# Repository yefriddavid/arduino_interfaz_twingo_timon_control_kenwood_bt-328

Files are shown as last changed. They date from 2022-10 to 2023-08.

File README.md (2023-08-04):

# Arduino Interfaz Twingo Timon Control Kenwood BT-328

### References:
- https://www.kenwood.com/pa/car/head_units/kmm-bt328/
- https://articulo.mercadolibre.com.co/MCO-555947676-control-de-audio-ve-interfaz-para-twingo-clio-y-symbol-_JM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
- https://github.com/bigevtaylor/arduino-swc
- https://www.instructables.com/Custom-Arduino-to-Keep-CAN-Steering-Wheel-Buttons-/
- https://www.youtube.com/watch?v=epe_4fnpTjk&ab_channel=JustinNelson%27sProjects
- https://github.com/tsprlng/toyota-kenwood-adaptor ## works
- http://drclone.blogspot.com/2015/01/controlar-autorradio-sony-con-los.html
- https://www.youtube.com/watch?v=6VO589mRQkM&ab_channel=TravisColesen
- https://www.youtube.com/watch?v=RdR43ACfeu8&t=257s&ab_channel=MentalidadDeIngenier%C3%ADa
- https://www.youtube.com/watch?v=d-j0onzzuNQ&t=305s&ab_channel=TheEngineeringMindset
- https://lastminuteengineers.com/esp8266-pinout-reference/
- https://randomnerdtutorials.com/esp8266-pinout-reference-gpios/
- https://www.kenwood.com/asia/car/Steering-remote/
- https://www.youtube.com/watch?v=fk73SCOE8qU&ab_channel=BartKuijper
- https://pastebin.com/fXbScxV4 // code with jvc and twingo
- https://init6.pomorze.pl/projects/kenwood_ford/

### Pinout
- https://lastminuteengineers.com/esp8266-pinout-reference/
- https://lededitpro.com/esp8266-pinout-guide-gpios/

### 

- https://www.youtube.com/watch?v=vRJ6ywV8bLI&ab_channel=Electr%C3%B3nicaAWV
- https://randomnerdtutorials.com/esp8266-pinout-reference-gpios/

### Commands
```
$ make upload
$ make compile
$ make just-compile
```

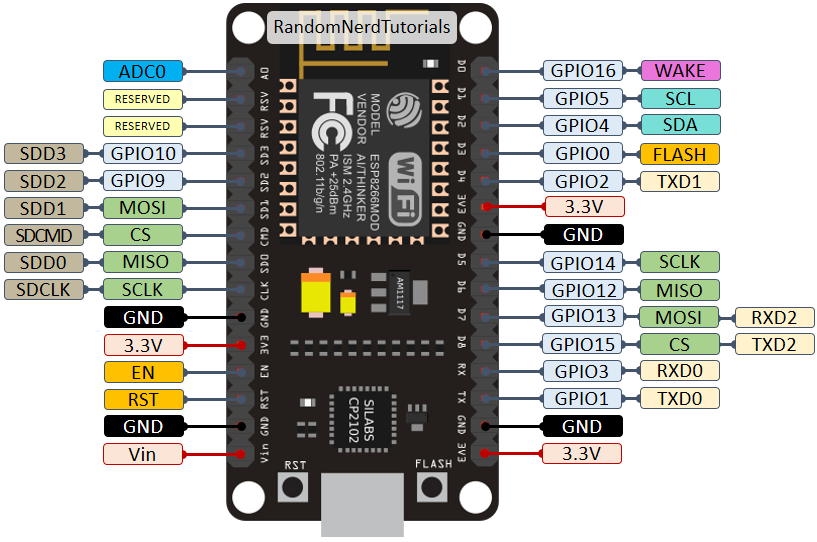
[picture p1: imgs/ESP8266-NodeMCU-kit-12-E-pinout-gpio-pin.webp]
ESP8266 Pins schema


| Pin		| Arnes Color 	| ESP8266 Pin	| Card	Control Color	|
|---|---|---|---|
| 4		| 	Green		| 	D2 	|	Green 		|
| 2	 	| 	White 		|	D4 	|	Brown 		|
| 15 	 	| 	Yellow		|	D8 	|	Yellow 		|
| 12 	 	| 	Blue		|	D6 	|	Light Blue 	|
| 13 		| 	White/Brown 	|	D7 	|	Black		|		
| 14 	 	| 	White/Orange 	|	D5 	|	Red 		|

| 	 Wire 	| Brown 	| 	Blak	| 	Red	|
|---|---|---|---|
| 	Green		| RULETA	| SKIP_FORWARD  | SOURCE |
| 	Yellow		| RULETA	| SKIP_BACKWARD  | VOL DOWN |
| 	Blue		| RULETA 	| MUTE | VOL UP |

```

D4 -> 2
D8 -> 15
D2 -> 4
D6 -> 12
D5 -> 14
D1 -> 5 -> Stereo Output -> kenwood

```

```
Red Wire -> Ignition stereo car
Black Wire -> Negative Stereo Wire harness
Yellow Wire -> light/blue Wire Stero Harness

```

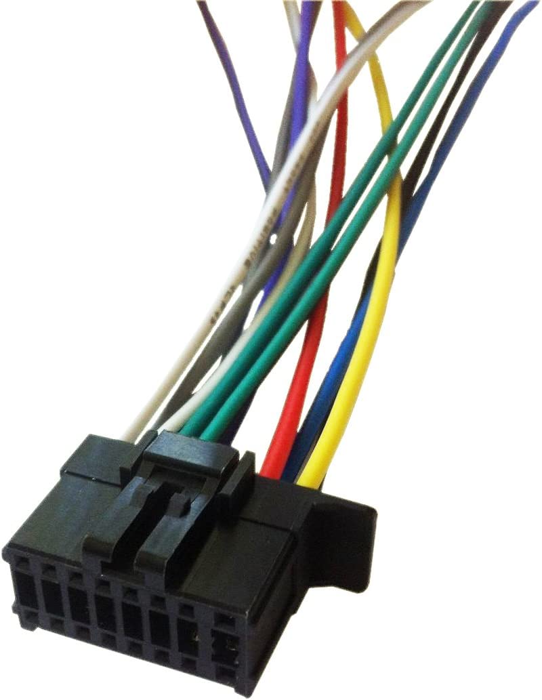
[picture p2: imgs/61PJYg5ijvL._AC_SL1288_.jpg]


### Command
<!--![Alt text](D_NQ_NP_670314-MLV45242759239_032021-O.jpg "ESP8266 Kenwood wires schema")-->

### Twingo Access

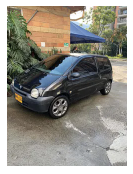
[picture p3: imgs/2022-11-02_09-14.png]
Twingo Access 2012


## New features
- beep: to know if the device started, from driver's seat

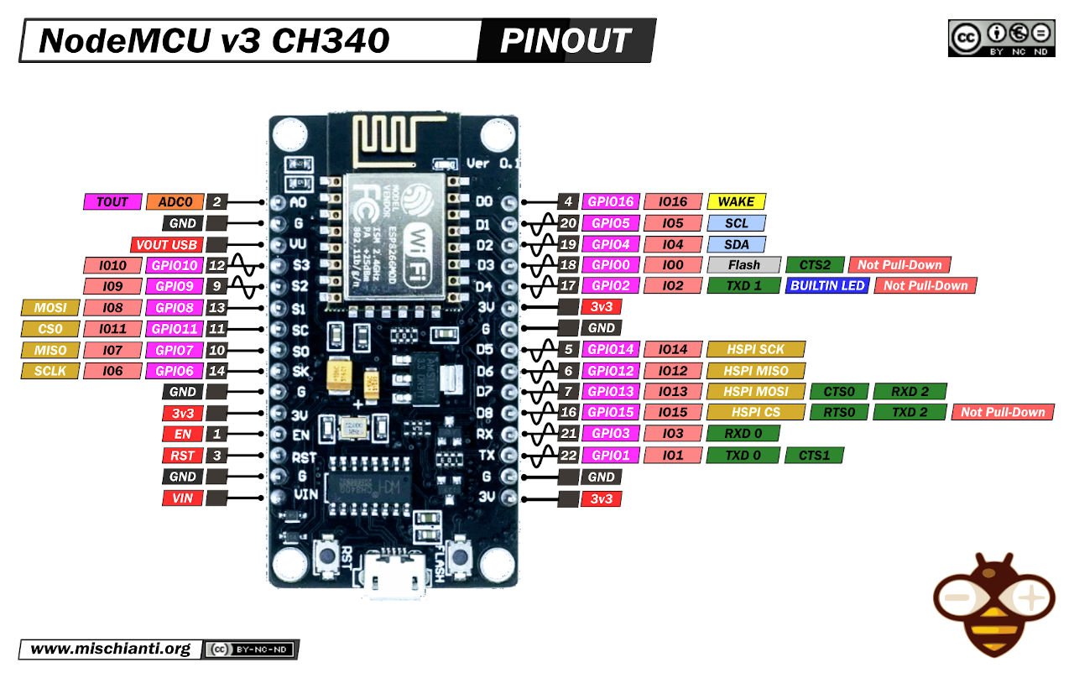
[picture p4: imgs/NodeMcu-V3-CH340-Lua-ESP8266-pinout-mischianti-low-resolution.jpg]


## Green Output (OK) only works for leds or something like
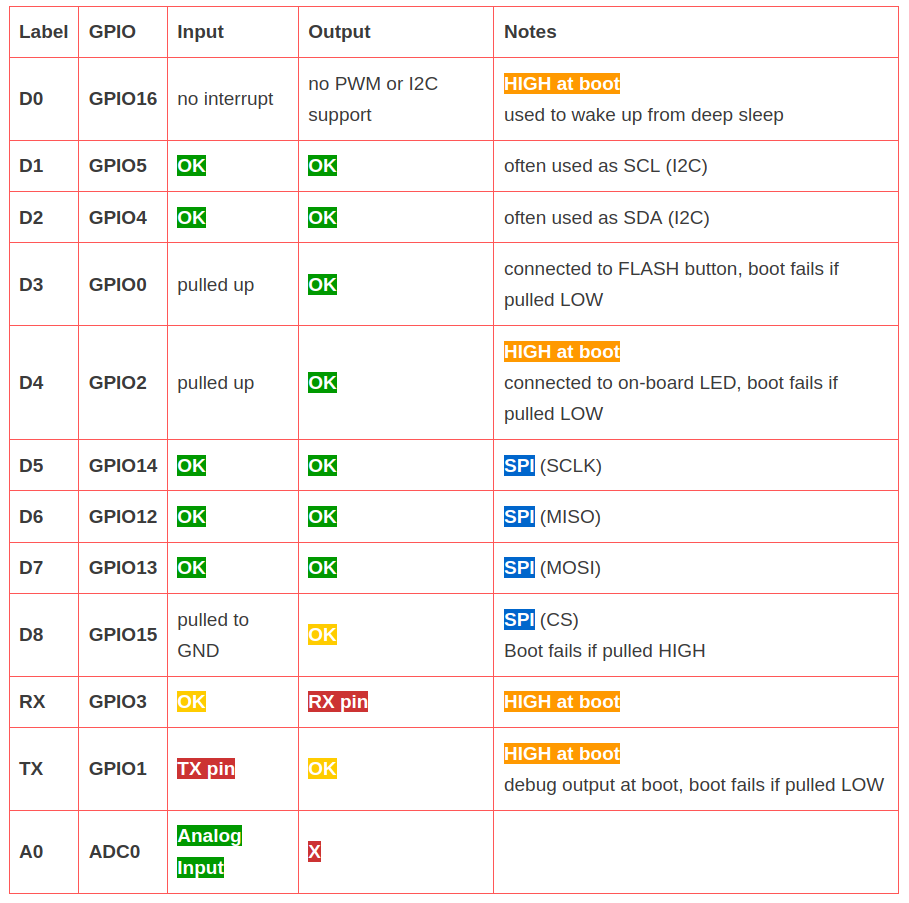
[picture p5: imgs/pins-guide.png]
Pins Guide


## Kendood BT-328
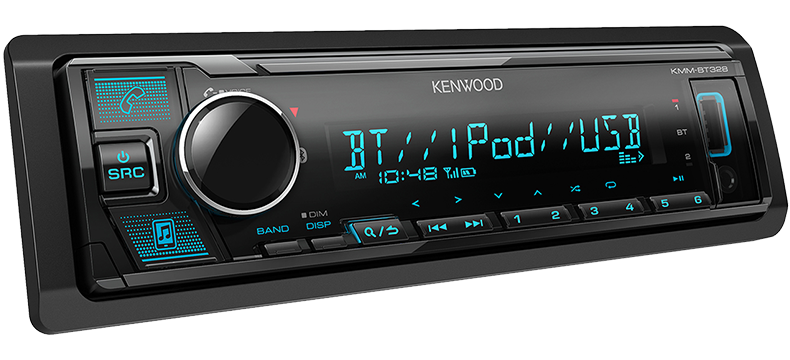
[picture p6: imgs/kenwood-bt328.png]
Kenwood BT328


## Twingo Timon Control
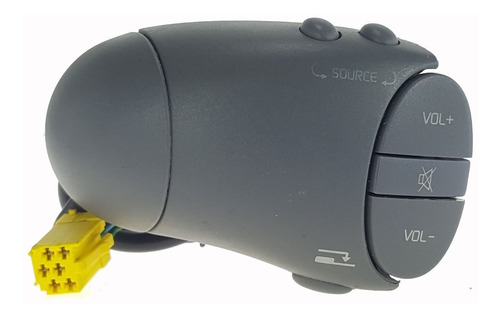
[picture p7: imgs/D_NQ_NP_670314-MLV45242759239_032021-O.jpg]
Twingo Control


## Case
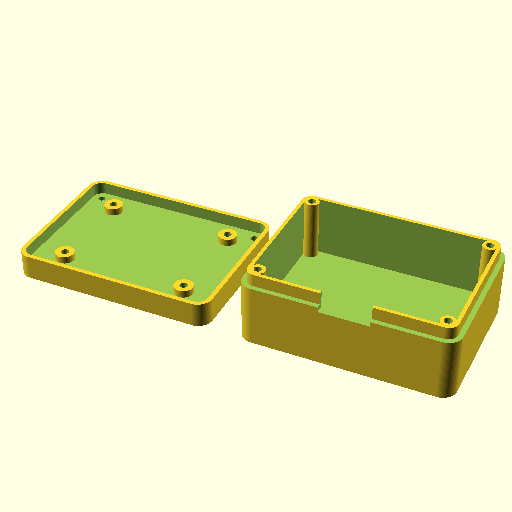
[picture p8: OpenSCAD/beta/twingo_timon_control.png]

## Wire
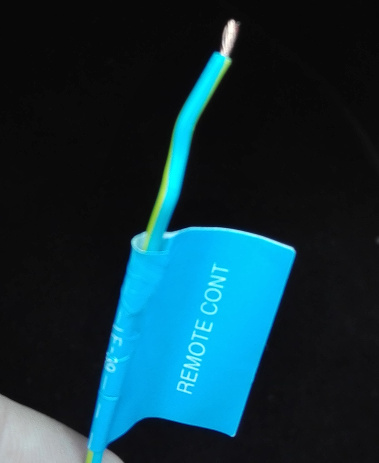
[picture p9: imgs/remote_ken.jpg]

## NEC
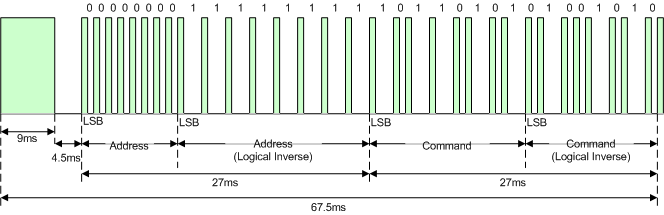
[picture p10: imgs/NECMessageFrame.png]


## PCB
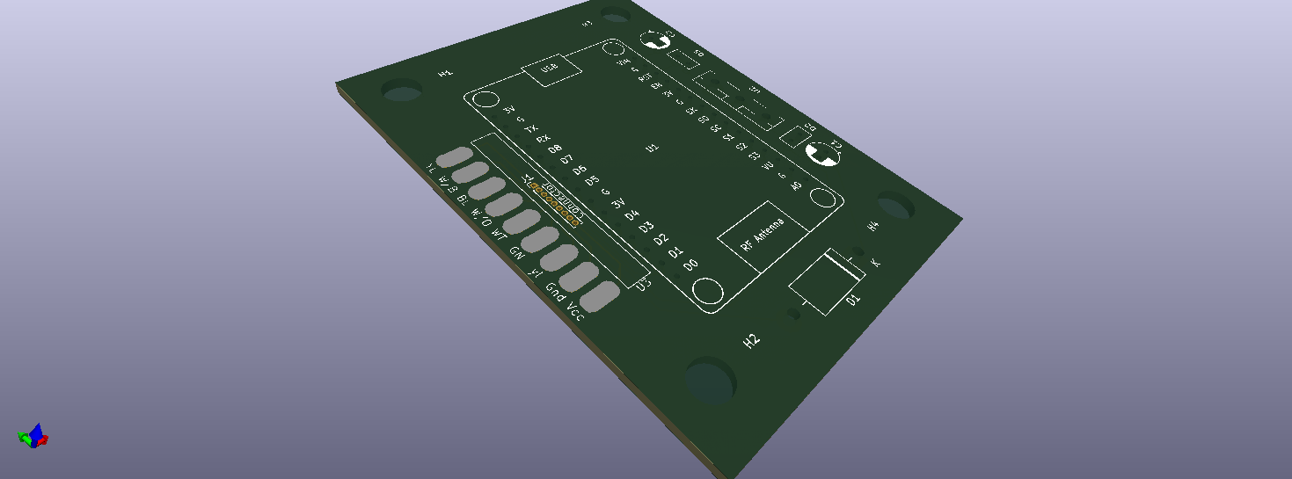
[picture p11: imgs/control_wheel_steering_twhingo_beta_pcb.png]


## PINOUT PWM
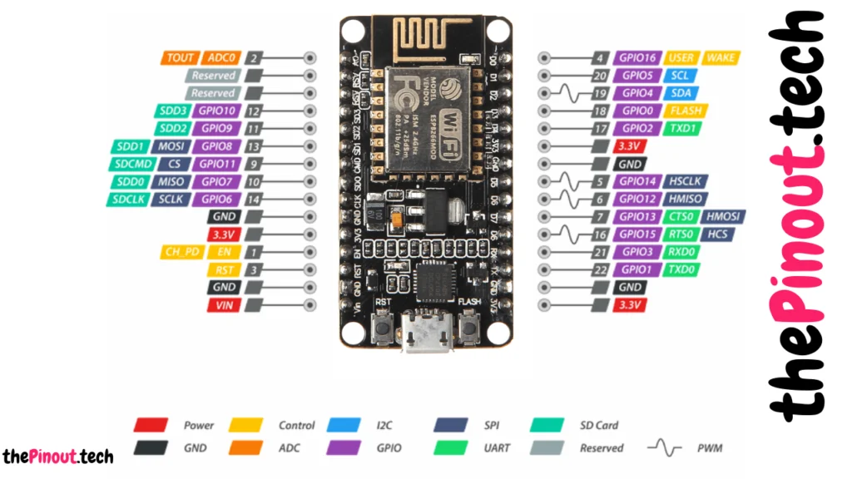
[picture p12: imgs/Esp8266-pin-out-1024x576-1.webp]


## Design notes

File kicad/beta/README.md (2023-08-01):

preguntas cristian

Regulador integrarlo o externo? temperatura del carro, ineficiente que es el actual.
pistas y caja en 3D

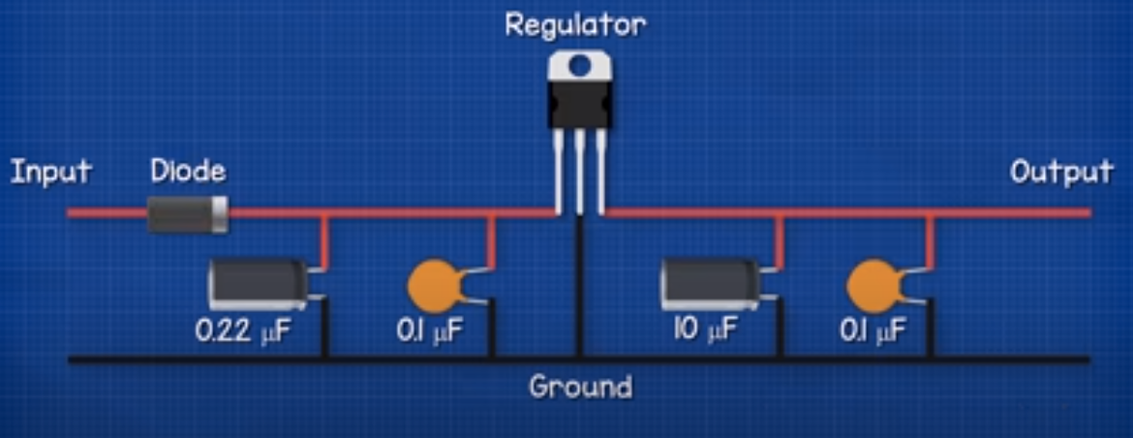
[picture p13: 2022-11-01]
imgs/schema-regulator.png

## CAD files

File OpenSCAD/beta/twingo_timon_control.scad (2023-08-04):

$fn=100;


//aspen = "gray";
//almond = "white";
//pine = "green";
//banyan="red";
//aspen = "";
aspen = "";//rgb(255, 0, 0);
almond = "";

pine = "";
banyan="";
altoSoporte = 3;



w=78; // Width
h=56; // Higth
d=25; //
wt=3.5;
bpt=5;
tpt=5;
cd=5;
cwt=1.5;

echo(d+bpt+tpt);
translate([-w/2-10,0,d+bpt+tpt+1])
rotate(a=180, v=[0,1,0])
lid();


translate([w/2+20,0,0])
box();


cx=0;
cy=0;
chs_i=1.5;
chs_o=4;
dsth=3;
chd_h=90;
chd_v=90;
tolerancia3D=0.3;
tolerancia=-0.2;
//--------------------------------------------------
//TOP PART MOUNTING HOLES
//--------------------------------------------------
//position
cx1=0;
cy1=0;
//holes size (radius)
chs_i1=1.6;
chs_o1=3;
//holes distance h
chd_h1=h-2*chs_i1-2;
//holes distance v
chd_v1=w-2*chs_i1-2;
//*************************************************//
//*************************************************//
//MODULES
//*************************************************//

//top box part
module lid()
{
        difference()
        {
            union()
            {
                difference()
                {
                    translate([ 0, 0, d+bpt-cd-0.2])
                    rounded_cube( w+2*wt, h+2*wt, tpt+cd+0.2, 6);

                    translate([ 0, 0,  d+bpt-cd-1])
                    rounded_cube( w+2*cwt+0.3, h+2*cwt+0.3, cd+1, 4);
                }
                /*************************/

                //add here...

                /*************************/
            }
            //TOP PART HOLES
            lid_hols();
            /*************************/

            //subtract here...

            lid_laterals_holes();
            /*************************/
	        lid_postes_holes_tuercas();
        }
    difference()
    {
        lid_postes();
	    lid_postes_holes();

    }
}

//bottom box
module box()
{
    difference()
    {
        union()
        {
            difference()
            {
                rounded_cube( w+2*wt, h+2*wt, d+bpt, 6);

                translate([ 0, 0, -cd])
                difference()
                {
                    translate([ 0, 0,  d+bpt])
                    rounded_cube( w+2*wt+1, h+2*wt+1, cd+1, 4);

                    translate([ 0, 0,  d+bpt-1])
                    rounded_cube( w+2*cwt, h+2*cwt, cd+3, 4);
                }
                translate([ 0, 0, bpt])
                rounded_cube( w, h, d+bpt, 4);
            }
            //BOARD DISTANCER
            //board_distancer();
            //TOP PLATE DISTANCER
            top_distancer();
            /*************************/

            //add here...

            /*************************/
        }

        //BOARD HOLES
        // bh_cut();
        //TOP PART HOLES
	// holes postes box
        tph_b_cut();
             box_laterals_holes();
        /*************************/

        //subtract here...

        /*************************/

    }

    //box_laterals_holes(); //preview
    // :w
    // soportes();
    left_support(40,40,3,5);
    right_support(40,40,3,5);

}

module left_support(side1,side2,corner_radius,triangle_height){
    translate([-77,0,0]){
    difference(){
  translate([5,0,0]){
    hull(){
    translate([17,0,0]) cylinder(r=corner_radius,h=triangle_height-1);
      x=side1 - corner_radius * 2;
      y=side2 - corner_radius * 2+5;
      echo(y);
    translate([x,-y+25,0]) cylinder(r=corner_radius,h=triangle_height-1);
    translate([x,y-25,0]) cylinder(r=corner_radius,h=triangle_height-1);
    }
  }

  // hole
  translate([28,0,-1])
//color("red")
cylinder(r=1.75,h=60);

    // base tornillo
  translate([28,0,3.5])
    cylinder(r=4,h=60);
  }
  }
}

module right_support(side1,side2,corner_radius,triangle_height){

    val = 10;

    x=side1 - corner_radius * 2 + val;
    y=side2 - corner_radius * 2+5;
    echo(x);
      translate([-25,0,0]){
    difference(){
  translate([15,0,0]){
    hull(){
    translate([63,0,0]) cylinder(r=corner_radius,h=triangle_height-1); // middle square

      //echo(y);
    translate([x,-y+25,0]) cylinder(r=corner_radius,h=triangle_height-1);
    translate([x,y-25,0]) cylinder(r=corner_radius,h=triangle_height-1);
    }
  }

  // hole
  translate([73,0,-1])
//color("red")
cylinder(r=1.75,h=60);
    // base tornillo
  //translate([28,0,3.5])
    //cylinder(r=4,h=60);
  translate([73,0,3.5])
cylinder(r=4,h=60);
  }
  }
}


module box_laterals_holes()
{
    translate([cx,cy,0])
    {
// x, y, z
        //ancho=25; // -13
        ancho=20; // -8

        x = ancho/2*-1;
        translate([x,-34,20])
        cube([ancho,10,11]);
        // original translate([+chd_h/2+-62,-34,23]) cube([ancho,10,8]);

    }

}
/****************************************************/
module lid_laterals_holes()
{
    translate([cx,cy,0])
    {

        translate([+chd_h/2-99,-10,24]) cube([3,19,5]);

    }
}
module lid_postes()
{

    translate([cx,cy,0])
    {

        z = 27;
        z = 29-altoSoporte;
        //z = 21;
        y1 = 19.5;// chd_v/2-25.5;
        //y2 = -chd_v/2+25.5;
        y2 = -19.5;
        alto=altoSoporte+dsth;
        echo("alto");
        echo(alto);

        correccion=7.5;
        //x2=-chd_h/2+18;
        x2=-28.5;// (w/4+correccion);
        //x1=+chd_h/2-18;
        //x1=+chd_h/2-18;
        // x1=w/4+correccion;
        x1=28.5;

        color(aspen) translate([x1,y1,z]) cylinder(r=chs_o,h=alto);
        color(pine) translate([x2,y1,z]) cylinder(r=chs_o,h=alto);
        color(almond) translate([x1,y2,z]) cylinder(r=chs_o,h=alto);
        color(banyan) translate([x2,y2,z]) cylinder(r=chs_o,h=alto);

    }


}

// Postes box
module top_distancer()
{
    translate([cx1,cy1,0])
    {
        translate([-chd_v1/2, chd_h1/2, 0])
        cylinder(r=chs_o1,h=d+bpt);
        translate([-chd_v1/2, -chd_h1/2, 0])
        cylinder(r=chs_o1,h=d+bpt);
        translate([chd_v1/2, chd_h1/2, 0])
        cylinder(r=chs_o1,h=d+bpt);
        translate([chd_v1/2, -chd_h1/2, 0])
        cylinder(r=chs_o1,h=d+bpt);
    }
}
module lid_postes_holes_tuercas()
{
    translate([cx,cy,0])
    {

        x=chd_h/2-16.5;
        translate([x,chd_v/2-25.5,35]) fhex(5.5,12);
        translate([-x,chd_v/2-25.5,35]) fhex(5.5,12);
        translate([-x,-chd_v/2+25.5,35]) fhex(5.5,12);
        translate([x,-chd_v/2+25.5,35]) fhex(5.5,12);

    }
}
module lid_postes_holes()
{
    translate([cx,cy,0])
    {

        // el tornillo tiene un diametro de 3 mas la tolerancia 0.3 => 3.3 / 2 = R
        translate([+chd_h/2-16.5,chd_v/2-25.5,24]) cylinder(r=1.65,h=bpt+dsth+2);
        translate([-chd_h/2+16.5,chd_v/2-25.5,24]) cylinder(r=1.65,h=bpt+dsth+2);
        translate([+chd_h/2-16.5,-chd_v/2+25.5,24]) cylinder(r=1.65,h=bpt+dsth+2);
        translate([-chd_h/2+16.5,-chd_v/2+25.5,24]) cylinder(r=1.65,h=bpt+dsth+2);
    }
}

module lid_hols()
{
    translate([cx1,cy1,0])
    {
        translate([-chd_v1/2, chd_h1/2, -2]) cylinder(r=chs_i1,h=d+bpt+tpt+3);
        translate([chd_v1/2, chd_h1/2, -2]) cylinder(r=chs_i1,h=d+bpt+tpt+3);

        translate([-chd_v1/2, -chd_h1/2, -2]) cylinder(r=chs_i1,h=d+bpt+tpt+3);
        translate([chd_v1/2, -chd_h1/2, -2])  cylinder(r=chs_i1,h=d+bpt+tpt+3);


        translate([-chd_v1/2, chd_h1/2, d+bpt+tpt-1.3])
        fhex(5.5,3);

        translate([chd_v1/2, chd_h1/2, d+bpt+tpt-1.3])
        fhex(5.5,3);

        translate([-chd_v1/2, -chd_h1/2, d+bpt+tpt-1.3])
        fhex(5.5,3);

        translate([chd_v1/2, -chd_h1/2, d+bpt+tpt-1.3])
        fhex(5.5,3);

    }
}
module tph_b_cut()
{
    translate([cx1,cy1,0])
    {
        // translate([-chd_v1/2, chd_h1/2, -2]) cylinder(r=chs_i1,h=d+bpt+3);
        translate([-chd_v1/2, chd_h1/2, -2]) cylinder(r=chs_i1,h=d+bpt+3);
        translate([chd_v1/2, chd_h1/2, -2]) cylinder(r=chs_i1,h=d+bpt+3);

        translate([-chd_v1/2, -chd_h1/2, -2]) cylinder(r=chs_i1,h=d+bpt+3);
        translate([chd_v1/2, -chd_h1/2, -2]) cylinder(r=chs_i1,h=d+bpt+3);

        translate([-chd_v1/2, chd_h1/2, -1]) cylinder(r=3,h=4);

        translate([chd_v1/2, chd_h1/2, -1]) cylinder(r=3,h=4);

        translate([-chd_v1/2, -chd_h1/2, -1]) cylinder(r=3,h=4);

        translate([chd_v1/2, -chd_h1/2, -1]) cylinder(r=3,h=4);

    }
}


module rounded_cube( x, y, z, r)
{
    translate([-x/2+r,-y/2+r,0])
    linear_extrude(height=z)
    minkowski()
    {
        square([x-2*r,y-2*r],true);
        translate([x/2-r,y/2-r,0])
        circle(r);

    }
}

module fhex(wid,height)
{
    hull()
    {
        cube([wid/1.7,wid,height],center = true);
        rotate([0,0,120])cube([wid/1.7,wid,height],center = true);
        rotate([0,0,240])cube([wid/1.7,wid,height],center = true);
    }
}

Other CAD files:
OpenSCAD/beta/generic_box_v2.scad

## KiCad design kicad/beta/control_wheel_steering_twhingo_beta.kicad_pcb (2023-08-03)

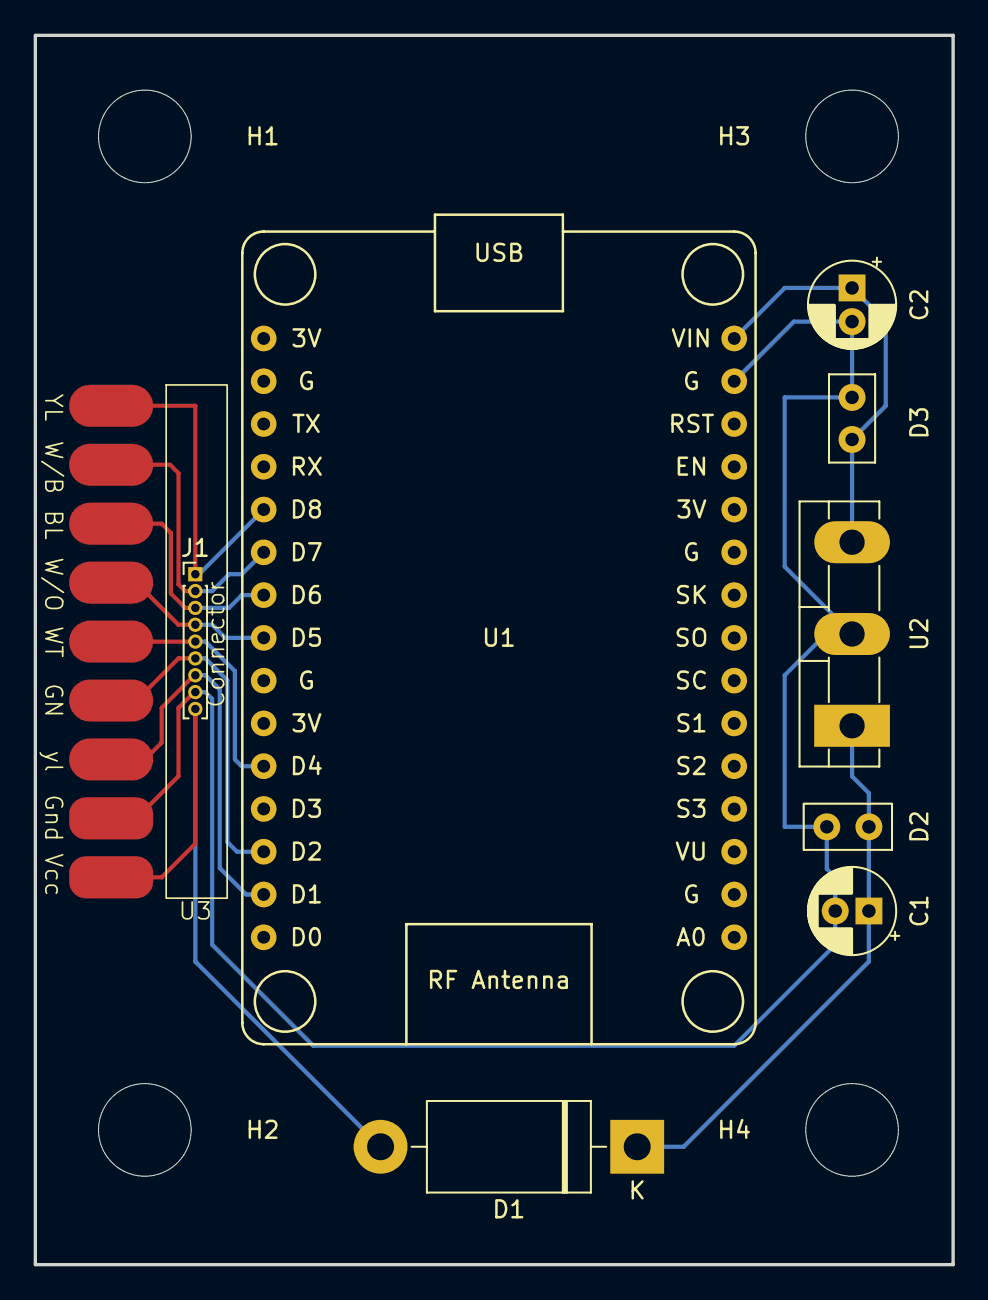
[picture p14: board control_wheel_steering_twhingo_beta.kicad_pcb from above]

Board: 2 copper layers, 54.5 x 73.0 mm, 13 parts (0 on the bottom side), 9 nets.

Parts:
C1: Cap2; CP_Radial_D5.0mm_P2.00mm
C2: C_Polarized; CP_Radial_D5.0mm_P2.00mm
D1: 1N5408; D_DO-201AD_P15.24mm_Horizontal
D2, D3: cap1; C_Disc_D5.0mm_W2.5mm_P2.50mm
H1, H2, H3, H4: MountingHole; MountingHole_5.5mm
J1: Conn_01x09_Socket; PinHeader_1x09_P1.00mm_Vertical
U1: NodeMCU_1.0_(ESP-12E); NodeMCU1.0(12-E)
U2: L7805; TO-3P-3_Vertical
U3: Twingo_Timon_Control_Connector

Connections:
D2Green: J1.6, U3.6 (D2)
D4-White: J1.5, U3.5 (D4)
D5-White/Orange: J1.4, U3.4 (D5)
D6-Blue: J1.3, U3.3 (D6)
D7-WhiteBrown: J1.2, U3.2 (D7)
D8-Yellow: J1.1, U3.1 (D8)
Gnd: J1.8, U3.8 (GND)
StereoOut: J1.7, U3.7 (StrOut)
VinCar: J1.9, U3.9 (Vin)

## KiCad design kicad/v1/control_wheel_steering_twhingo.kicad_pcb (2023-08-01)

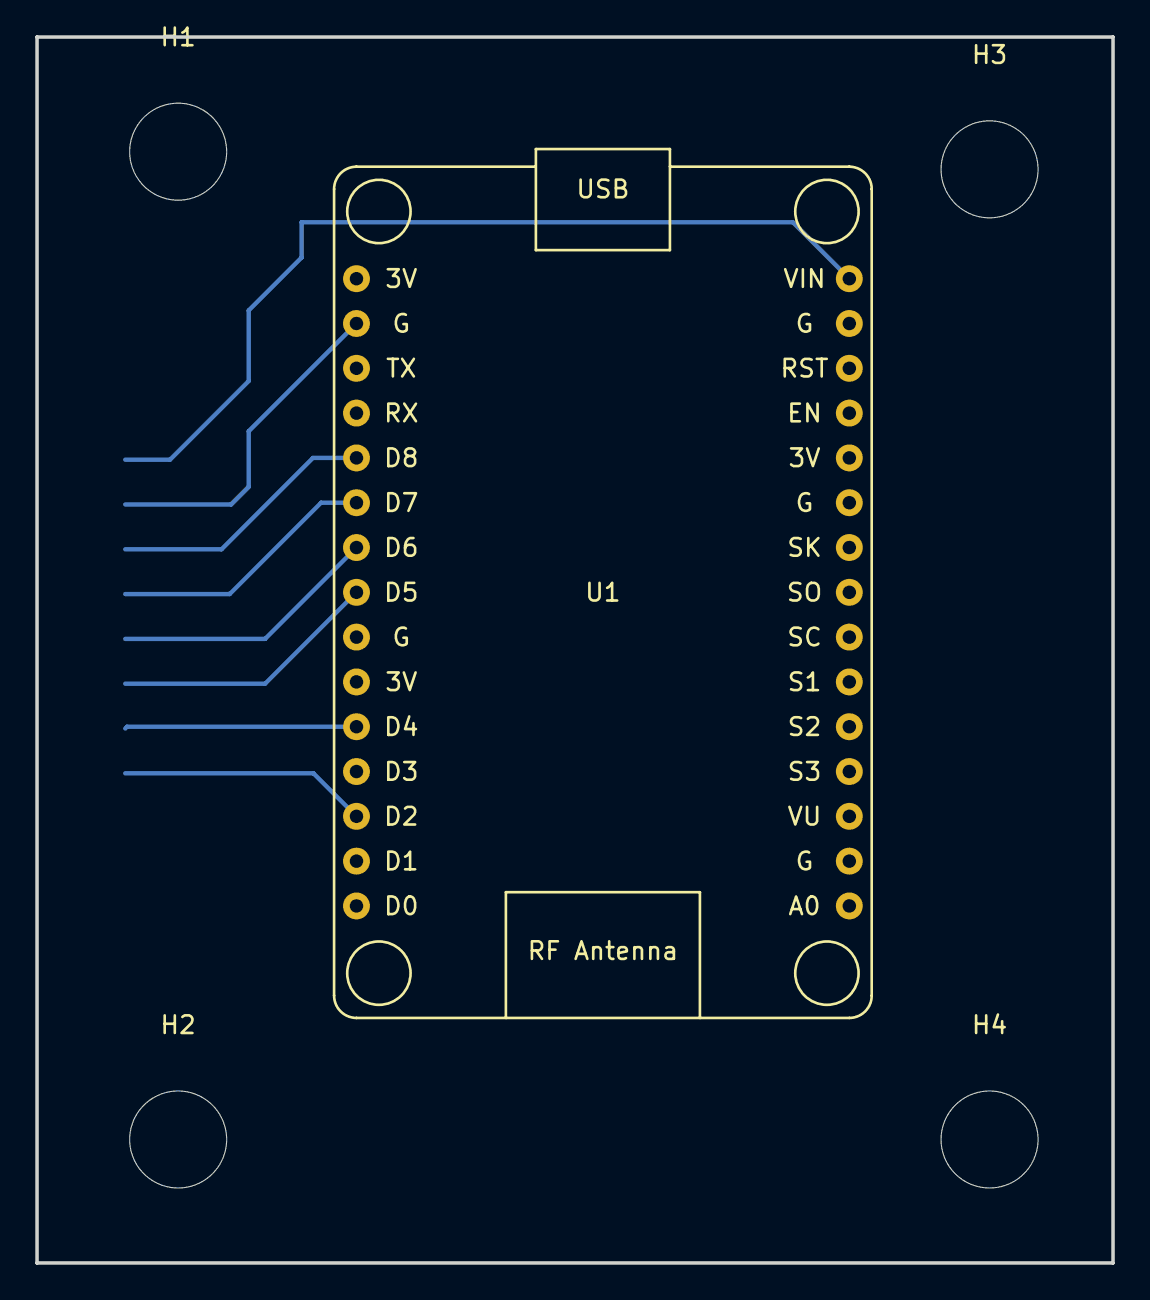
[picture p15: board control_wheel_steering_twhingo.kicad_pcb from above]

Board: 2 copper layers, 61.0 x 69.5 mm, 6 parts (1 on the bottom side), 8 nets.

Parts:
H1, H2, H3, H4: MountingHole; MountingHole_5.5mm
J1: Conn_01x09_Socket; Harting_har-flexicon_14110813010xxx_1x08-MP_P2.54mm_Horizon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
U1: NodeMCU_1.0_(ESP-12E); NodeMCU1.0(12-E)

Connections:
D2-White: J1.8, U1.28 (D2(GPIO4))
D4-Brawn: J1.7, U1.26 (D4(GPIO2))
D5-Red: J1.6, U1.23 (D5(GPIO14))
D6-Blue: J1.5, U1.22 (D6(GPIO12))
D7-White/Orange: J1.4, U1.21 (D7(GPIO13))
D8-Yellow: J1.3, U1.20 (D8(GPIO15))
GND: J1.2, U1.17 (GND)
Vin: J1.1, U1.15 (VIN)

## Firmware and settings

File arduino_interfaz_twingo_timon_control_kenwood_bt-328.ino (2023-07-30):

/* 				Twingo Stering Wheel Audio Stereo Contro For Keenwood 					*/
/*------------------+---------------+-------------------+-----------------------+---------------+-----------------------+*/
/*================= | Code Variable |	    Pin		|     Arnes Color 	|   Board Pin 	| 	Control Color	|*/
/*------------------+---------------+-------------------+-----------------------+---------------+-----------------------+*/
static const uint8_t pinVerde 	 = 	4; 	// 	| 	Green		| 	D2 	|	Green 		|
static const uint8_t pinMarron 	 = 	2; 	// 	| 	White 		|	D4 	|	Brown 		|
static const uint8_t pinAmarillo = 	15; 	// 	| 	Yellow		|	D8 	|	Yellow 		|
static const uint8_t pinAzul 	 = 	12; 	// 	| 	Blue		|	D6 	|	Light Blue 	|
static const uint8_t pinNegro 	 = 	13; 	//	| 	White/Brown 	|	D7 	|	Black		|
static const uint8_t pinRojo 	 = 	14; 	// 	| 	White/Orange 	|	D5 	|	Red 		|
/*------------------------------------------------------+---------------+---------------+-------------------------------+*/

static const uint8_t stereoOutput = 5; // output -> yellow D1

int azul;
int verde;
int rojo;
int negro;
int amarillo;
int marron, ruletaSiguiente, ruletaAnterior, ruletaActual;
int pulsado, mantiene;

static int ZERO = 0;
static int VOL_UP = 1;
static int VOL_DOWN = 2;
static int SKIP_BACKWARD = 3;
static int SKIP_FORWARD = 4;
static int PLAY_PAUSE = 5;
static int MUTE = 6;
static int SOURCE = 7;

const String KenwoodCommDescriptionArray[10] = {
  "zero",
  "Volume up",
  "Volume down",
  "Skip forward",
  "Skip backward",
  "Play/pause",
  "Mute",
  "Source"
};

void setup()
{

  // Por defecto los pins de entrada en HIGH (PULLUP)
  pinMode(pinMarron, INPUT_PULLUP); 	// for wheel
  pinMode(pinNegro, INPUT_PULLUP); 	// for buttons
  pinMode(pinRojo, INPUT_PULLUP); 	// for buttons

  pinMode(pinAzul, OUTPUT);
  pinMode(pinVerde, OUTPUT);
  pinMode(pinAmarillo, OUTPUT);

  pinMode(stereoOutput, OUTPUT); // For send kenwood commands

  //inicializamos pines a LOW.
  digitalWrite(pinAzul, LOW);
  digitalWrite(pinVerde, LOW);
  digitalWrite(pinAmarillo, LOW);

  // Serial.begin(9600);
  // delay(10000);
  inicializaRuleta();

}



void loop()
{
  readButtonActions();
}

void readButtonActions() {
  // delay(200);
  delay(250);
  rojo = digitalRead(pinRojo);
  negro = digitalRead(pinNegro);

  if (negro == LOW) // se van leyendo los pines maestros para ver si cambian de estado..
  {
    Serial.println("Black:");
    pulsado = compruebaPinPulsado(pinNegro);
    if (pulsado == pinAzul)
    {
      SendKenwoodMessage(MUTE);
    }
    else if (pulsado == pinVerde)
    {
      SendKenwoodMessage(SKIP_BACKWARD);
    }
    else if (pulsado == pinAmarillo)
    {
      SendKenwoodMessage(SKIP_FORWARD);
    }

  }
  else if (rojo == LOW)
  {
    Serial.println("Red:");
    pulsado = compruebaPinPulsado(pinRojo);
    if (pulsado == pinAzul)
    {
      SendKenwoodMessage(VOL_UP);
    }
    else if (pulsado == pinVerde)
    {
      SendKenwoodMessage(SOURCE);
    }
    else if (pulsado == pinAmarillo)
    {
      SendKenwoodMessage(VOL_DOWN);
    }
  }
  
  compruebaRuleta();
}


void compruebaRuleta()
{
  marron = compruebaPinPulsado(pinMarron);
  if (marron != ruletaActual) //COMPROBAMOS SI HA CAMBIADO EL ESTADO DE LA RULETA (SI SE HA GIRADO)
  {
    delay(10);
    if (marron == ruletaSiguiente) //sube una pista Y REORDENAMOS VARIABLES
    {
      SendKenwoodMessage(SKIP_FORWARD);
      ruletaSiguiente = ruletaAnterior;
      ruletaAnterior = ruletaActual;
      ruletaActual = marron;
    }
    else if (marron == ruletaAnterior) //baja una pista Y REORDENAMOS VARIABLES.
    {
      SendKenwoodMessage(SKIP_BACKWARD);
      
      ruletaAnterior = ruletaSiguiente;
      ruletaSiguiente = ruletaActual;
      ruletaActual = marron;
    }
  }
}

void inicializaRuleta()  //LEEMOS EL ESTADO INICIAL DE LA RULETA AL ENCENDER LA RADIO.
//Y ESTABLECEMOS LOS COLORES QUE SERÁN LA SIGUIENTE O LA ANTERIOR PISTA (Y EL ACTUAL)
{
  ruletaActual = compruebaPinPulsado(pinMarron);
  if (ruletaActual == pinVerde)
  {
    ruletaSiguiente = pinAzul;
    ruletaAnterior = pinAmarillo;
  }
  else if (ruletaActual == pinAzul)
  {
    ruletaSiguiente = pinAmarillo;
    ruletaAnterior = pinVerde;
  }
  else if (ruletaActual == pinAmarillo)
  {
    ruletaAnterior = pinAzul;
    ruletaSiguiente = pinVerde;
  }
}

int compruebaPinPulsado(int pinBuscado)
{
  
  digitalWrite(pinAzul, HIGH);
  if (digitalRead(pinBuscado) == HIGH)
  {
    pulsado = pinAzul;
    digitalWrite(pinAzul, LOW);
    return pulsado;
  }
  
  digitalWrite(pinAzul, LOW);
  digitalWrite(pinVerde, HIGH);
  if (digitalRead(pinBuscado) == HIGH)
  {
    pulsado = pinVerde;
    digitalWrite(pinVerde, LOW);
    return pulsado;
  }

  digitalWrite(pinVerde, LOW);
  digitalWrite(pinAmarillo, HIGH);
  if (digitalRead(pinBuscado) == HIGH)
  {
    pulsado = pinAmarillo;
  }
  digitalWrite(pinAmarillo, LOW);
  return pulsado;
}

byte KenwoodData; //variable initializer for data that will be sent to Kenwood stereo
byte CarSWbuttonInput = 0; //initialize variable that will switch through different commands
int before_millis;

void SendKenwoodMessage(int messageId) {
  CarSWbuttonInput = messageId;
  PrepareKenwoodMessage();
  Serial.println(KenwoodCommDescriptionArray[messageId]);

  int diff = millis() - before_millis;
  //Serial.println(diff);

  //Serial.println(before_millis);


  before_millis = millis();
}

void PrepareKenwoodMessage() {
  const byte KenwoodAddress = B10111001;

  const byte KenwoodCommArray[10] = {
    B00000000,  // 0) 00000000 11111111 zero
    B00010100,  // 1) 00101000 11010111 Volume up
    B00010101,  // 2) 10101000 01010111 Volume down
    B00001011,  // 3) 11010000 00101111 Skip forward
    B00001010,  // 4) 01010000 10101111 Skip backward
    B00001110,  // 5) 01110000 10001111 Play/pause
    B00010110,  // 6) 01101000 10010111 Mute
    B00010011
  }; // 7) 11001000 00110111 Source

  byte KenwoodCommand;
  switch (CarSWbuttonInput) {
    case 0:    break; /*do nothing currently*/
    case 1:    KenwoodCommand = KenwoodCommArray[1]; break;   //Volume up
    case 2:    KenwoodCommand = KenwoodCommArray[2]; break;   //Volume down
    case 3:    KenwoodCommand = KenwoodCommArray[3]; break;   //Skip Forward
    case 4:    KenwoodCommand = KenwoodCommArray[4]; break;   //Skip Backward
    case 5:    KenwoodCommand = KenwoodCommArray[5]; break;   //1-6 button - Play/Pause
    case 6:    KenwoodCommand = KenwoodCommArray[6]; break;   //Mute
    case 7:    KenwoodCommand = KenwoodCommArray[7]; break;   //Source
  }

  digitalWrite(stereoOutput, LOW);     delayMicroseconds(9000); //turn ON for 9ms for Start
  digitalWrite(stereoOutput, HIGH);    delayMicroseconds(4500); //turn OFF for 4.5ms for Start

  KenwoodData = KenwoodAddress;
  SendKenwoodBinary();  // Send Device Address
  KenwoodData = KenwoodCommand;
  SendKenwoodBinary();

  digitalWrite(stereoOutput, LOW);     delayMicroseconds(562); // prender para finalizar
  digitalWrite(stereoOutput, HIGH);    // apagar para finalizar

}

/*****************************************************************************/
void SendKenwoodBinary() {
  byte bit;

  for (byte i = 1; i <= 2; i++) {
    if (i == 2) {
      KenwoodData = ~KenwoodData;
    }

    for (byte X = 0; X <= 7; X++) {
      bit = bitRead(KenwoodData, X); //bitRead starts with LSB (least significant bit), meaning it reads right-most bit moving leftward
      if (bit == 0) {
        digitalWrite(stereoOutput, LOW);     delayMicroseconds(562);  //keep ON for 562.5us
        digitalWrite(stereoOutput, HIGH);    delayMicroseconds(562);  //keep OFF for 562.5us
      }
      else {  //(bit == 1)
        digitalWrite(stereoOutput, LOW);     delayMicroseconds(562);  //keep ON for 562.5us
        digitalWrite(stereoOutput, HIGH);    delayMicroseconds(1687); //keep OFF for 1687.5us
      }
    }
  }
}

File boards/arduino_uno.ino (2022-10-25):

#include <SPI.h>

int pinNegro = 8;
int pinMarron = 10;
int pinRojo = 6;
int pinAzul = 11;            
int pinVerde =7;
int pinAmarillo = 9;

// asignamos variables para almacenar estado de los pines conectados a los cables del mando
int azul;
int verde;
int rojo;
int negro;
int amarillo;
// ruletaSiguiente almacenará la posición que subiría pista desde la posición actual, Anterior la anterior y la ruletaActual, almacenará
// el color del cable que está tocando en el momento actual el codificador rotatorio, junto con el marrón (el común que siempre toca).
int marron, ruletaSiguiente, ruletaAnterior, ruletaActual;
// pulsado almacenará el nº (color) del pin que corresponde al botón pulsado del mando.
// mantiene chequea si hemos soltado o no el botón pulsado. Por ejemplo,
// si se mantiene el botón src, la radio se apagará.
int pulsado,mantiene;

#include "GPIO.h" //library I'm using for very fast digital pin control without needing to do direct port manipulation
GPIO<BOARD::D2> Kenw; //shortening Kenwood to Kenw so there will be less characters in functions


byte KenwoodData; //variable initializer for data that will be sent to Kenwood stereo

//byte CarSWbuttonInput = 0; //initialize variable that will switch through different commands



void setup() 
{
  Kenw.output(); //used with GPIO library for very fast digital pin control without using direct port manipulation
  Kenw = HIGH; //initialize to HIGH, because switching it LOW is for actual communications
  Kenw.input(); //change to input so that pin is floating, so IR remote can still function... turn back to OUTPUT to send a command

  
  //Se inicializan los pines conectados a los cables maestros del mando en modo pull up, es decir,
  //se mantienen en estado HIGH por defecto (mejora la fiabilidad de las señales en caso de ruido eléctrico)
  //se establecen como pines de entrada para leer la posible pulsación del azul, verde o amarillo,
  //que se usarán como pines de salida.
  pinMode(pinMarron, INPUT_PULLUP); // Por defecto los pins de entrada en HIGH (PULLUP)
  pinMode(pinNegro, INPUT_PULLUP);
  pinMode(pinRojo, INPUT_PULLUP);

  pinMode(pinAzul, OUTPUT);
  pinMode(pinVerde, OUTPUT);
  pinMode(pinAmarillo, OUTPUT);

//inicializamos pines a LOW.
  digitalWrite(pinAzul, LOW);
  digitalWrite(pinVerde, LOW);
  digitalWrite(pinAmarillo, LOW);

  Serial.begin(9600);
  // delay(10000);
  inicializaRuleta();

}


void loop() 
{

  delay(100);
 //delay(250); //introducimos un retardo de 250 ms para resolver ciertos problemas de sincronismo con la ruleta.
            // aún así, en alguna ocasión puntual al avanzar pista retrocede o viceversa.
 rojo = digitalRead(pinRojo); //leemos el estado del pin rojo y pin negro
 negro = digitalRead(pinNegro); //más abajo leemos la ruleta
 
 if (negro == LOW) // se van leyendo los pines maestros para ver si cambian de estado..
  {               
    pulsado = compruebaPinPulsado(pinNegro);
   // Serial.print(pulsado);
    if (pulsado == pinAzul)
    {
      // teclaMute();    // NEGRO + AZUL = MUTE  
      KenwoodOutput(6);
      Serial.println("Mute");
    }
    else if (pulsado == pinVerde)
      {
        //teclaSRCMas(); // NEGRO + VERDE = BOTON SRC+
        KenwoodOutput(3);
        Serial.println("src +");
      }
    else if (pulsado == pinAmarillo)
      {
       // teclaSRCMenos();   // NEGRO + AMARILLO = BOTON SRC-
       KenwoodOutput(4);
       Serial.println("src -");
      }
  
 }
 else if (rojo == LOW)
 {
    // Serial.println("LOW");
  
    pulsado = compruebaPinPulsado(pinRojo);
    if (pulsado == pinAzul)
      {
       //teclaVolMas(); // ROJO + AZUL = BOTON VOL+
         KenwoodOutput(1);
       Serial.println("Volume Up");
       // SPI.transfer(21);
      }
     else if (pulsado == pinVerde)
      {
               Serial.println("burcar emisoras");

        KenwoodOutput(7);
        //teclaSalto();  // ROJO + VERDE = BOTON SALTO CD
      }
      else if (pulsado == pinAmarillo)
      {
       //teclaVolMenos();   //ROJO + AMARILLO = BOTON VOL-
         KenwoodOutput(2); // este se queda
       Serial.println("Volume Down");
      }
 }
  
 //Serial.println(pulsado);
  //pulsado = 0;
  compruebaRuleta();
  
}


void compruebaRuleta()
{
  marron = compruebaPinPulsado(pinMarron);
  if (marron != ruletaActual) //COMPROBAMOS SI HA CAMBIADO EL ESTADO DE LA RULETA (SI SE HA GIRADO)
  {
    delay(10);
    if (marron == ruletaSiguiente) //sube una pista Y REORDENAMOS VARIABLES
    {
       //teclaRuletaMas();
       Serial.println("ruedita abajo");
       KenwoodOutput(4);
       ruletaSiguiente = ruletaAnterior;
       ruletaAnterior = ruletaActual;
       ruletaActual = marron; 
    }
    else if (marron == ruletaAnterior) //baja una pista Y REORDENAMOS VARIABLES.
    {
       // teclaRuletaMenos();
       Serial.println("ruedita arriba");
       KenwoodOutput(3);
       ruletaAnterior = ruletaSiguiente;
       ruletaSiguiente = ruletaActual;
       ruletaActual = marron; 
    }
  }
}

void inicializaRuleta()  //LEEMOS EL ESTADO INICIAL DE LA RULETA AL ENCENDER LA RADIO.
                          //Y ESTABLECEMOS LOS COLORES QUE SERÁN LA SIGUIENTE O LA ANTERIOR PISTA (Y EL ACTUAL)
  {
    ruletaActual = compruebaPinPulsado(pinMarron);
    if (ruletaActual == pinVerde)
    {
      ruletaSiguiente = pinAzul;
      ruletaAnterior = pinAmarillo;
    }
    else if (ruletaActual == pinAzul)
    {
      ruletaSiguiente = pinAmarillo;
      ruletaAnterior = pinVerde;
    }
    else if (ruletaActual == pinAmarillo)
    {
      ruletaAnterior=pinAzul;
      ruletaSiguiente=pinVerde;
    }
  }




int compruebaPinPulsado(int pinBuscado)
{
  digitalWrite(pinAzul, HIGH);
  if (digitalRead(pinBuscado) == HIGH)
    {
      pulsado = pinAzul;
    }
  digitalWrite(pinAzul, LOW);
  digitalWrite(pinVerde, HIGH);
  if (digitalRead(pinBuscado) == HIGH)
    {
      pulsado = pinVerde;
    }

  digitalWrite(pinVerde, LOW);
  digitalWrite(pinAmarillo, HIGH);
  if (digitalRead(pinBuscado) == HIGH)
   {
    pulsado = pinAmarillo;
   }
   digitalWrite(pinAmarillo, LOW);
   return pulsado;
 }
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

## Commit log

2022-10-27 first version with bug with vol up run sometimes source too
    [arduino_interfaz_twingo_timon_control_kenwood_bt-328.ino]
2022-11-01 docs: wires
2023-08-01 implement kicad files
    [control_wheel_steering_twhingo.kicad_pcb, control_wheel_steering_twhingo.kicad_sch, control_wheel_steering_twhingo_beta.kicad_pcb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]
2023-08-01 openscad added
    [generic_box_v2.scad]
2023-08-01 polish directory
    [control_wheel_steering_twhingo.kicad_pcb, control_wheel_steering_twhingo.kicad_sch, control_wheel_steering_twhingo_beta.kicad_pcb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]
2023-08-02 openscad added beta
    [box.scad, cover.scad, empty_box.scad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]
2023-08-03 3d box avances
    [generic_box_v2.scad]
2023-08-03 improve 3d case
    [box.scad, control_wheel_steering_twhingo_beta.kicad_pcb, cover.scad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]
2023-08-04 improve 3d box
    [twingo_timon_control.scad]
